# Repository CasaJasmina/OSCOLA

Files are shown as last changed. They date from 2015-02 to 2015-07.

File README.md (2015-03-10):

# OSCOLA
Open Source COnnected LAmp

Oscola is a open source connected lamp designed for the first Casa Jasmina workshop by [Jesse Howard](http://www.jessehoward.net/), Stefano Paradiso and Lorenzo Romagnoli. 

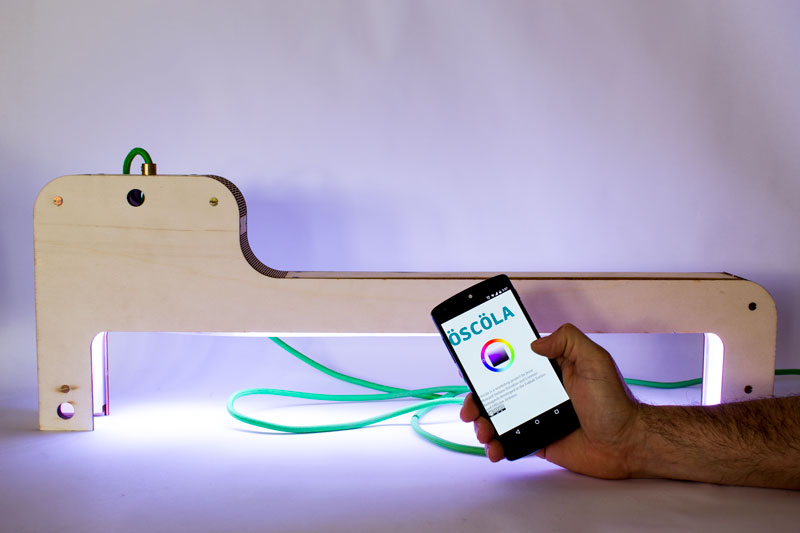
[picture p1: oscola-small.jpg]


Coherently with the Open-Design philosophy, the lamp can be easily reinterpreted and modified according to specific needs. 
The Structure of the lamp is meant to be laser-cutted, and his kept together with screws and bolts; no glue is needed.

The electronic of the lamp is based on Arduino YUN, hence it allows it to connect to the Internet. Via a web-interface the user can change the color of the light.
 
During the workshop participants, made their derivative design. Their codes and cutting files can be found in the "ws projects" folder.



The Arduino code uses MQTT and the [Easy-Arduino-Yun-MQTT-Client](https://github.com/bobbytech/Easy-Arduino-Yun-MQTT-Client) library. In order to control the addressable leds remember to download and install also the [Neopixel library](https://github.com/adafruit/Adafruit_NeoPixel) 

more pics from the workshop [here](https://www.flickr.com/photos/arduino_cc/sets/72157650751710580)

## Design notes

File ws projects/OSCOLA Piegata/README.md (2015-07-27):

# OSCOLA Piegata

CC BY-SA [tamberg](https://twitter.com/tamberg)

Derivative of [https://github.com/CasaJasmina/OSCOLA](https://github.com/CasaJasmina/OSCOLA) licensed CC BY-SA Jesse Howard, Stefano Paradiso and Lorenzo Romagnoli, developed at FabLab Torino and Officine Arduino.



## Arduino Yun Mailbox HTTP API

The OSCOLA Piegata Arduino code is based on the Arduino Yun [Mailbox HTTP API](https://www.arduino.cc/en/Tutorial/MailboxReadMessage), which is simpler than MQTT.

## Testing the API with Curl

Download and install the Curl command line tool from [http://curl.haxx.se/](http://curl.haxx.se/), then type

`$ curl -vX POST http://arduino.local/mailbox/{rrggbb}` e.g.

`$ curl -vX POST http://arduino.local/mailbox/ee6600`

## Using a DIY 3D Tilt Sensor Controller

This project includes a Web page with JS glue code for a [DIY 3D Tilt Sensor](http://www.instructables.com/id/DIY-3D-Tilt-Sensor/) controller - here's a [short video](https://www.youtube.com/v/HGzyO5u3bwg?start=170&end=186&version=3).

## Connecting to the IFTTT Maker Channel

Thanks to the HTTP API, the OSCOLA Piegata can receive Webhook calls from the [IFTTT Maker Channel](blog.ifttt.com/post/121786069098/introducing-the-maker-channel).

To make the Arduino Yun accessible from IFTTT follow the steps in [https://yaler.net/arduino-yun](https://yaler.net/arduino-yun)

Then [clone](https://ifttt.com/recipes/search?q=OSCOLA) or [create a new recipe](https://ifttt.com/myrecipes/personal/new) or [Do app](https://ifttt.com/products/do/button) button using your relay domain in the URL

`http://{RELAY_DOMAIN}.try.yaler.net/mailbox/{rrggbb}` e.g.

`http://gsiot-ffmq-ttd5.try.yaler.net/mailbox/ee6600`

Use *Method* `POST` and *Content Type* `application/x-www-form-urlencoded`, leave *Body* empty.

Here's an example recipe to [light up OSCOLA on sunset](https://ifttt.com/recipes/310542-light-up-oscola-on-sunset) at your location, and one to [switch off OSCOLA on sunrise](https://ifttt.com/recipes/310547-switch-off-oscola-on-sunrise).



IFTTT does not yet allow to publish Do app recpies, so you'll have to create one from scratch.

&nbsp;


# HTTP APIs and Webhooks for an open IoT

Note that OSCOLA, the DIY controller and the IFTTT platform do not know anything about each other.

[HTTP](http://tools.ietf.org/html/rfc2616)(S) [REST](https://de.wikipedia.org/wiki/Representational_State_Transfer) APIs and [Webhooks](https://en.wikipedia.org/wiki/Webhook) enable a loosely coupled, more open Internet of Things.

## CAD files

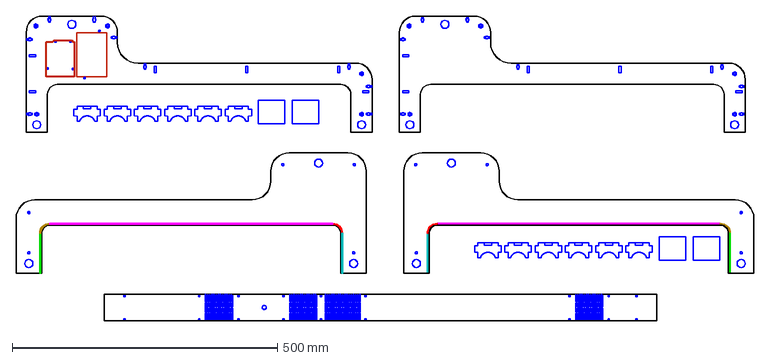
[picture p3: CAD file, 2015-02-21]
cuttingFiles/oscola.dxf
1390.3 x 574.4 mm

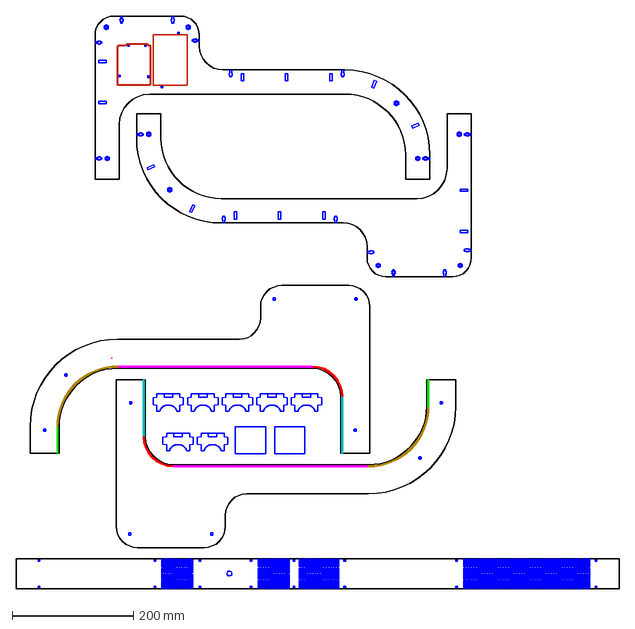
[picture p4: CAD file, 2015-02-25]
ws projects/OSCOLA Piegata/design/oscola_piegata.dxf
994.1 x 944.4 mm

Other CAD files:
ws projects/OSCOLA Piegata/design/oscola_piegata.3dm
ws projects/OSCOLA Piegata/design/oscola_piegata.skp

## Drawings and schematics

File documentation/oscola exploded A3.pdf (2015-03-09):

# OSCOLA

### opensource

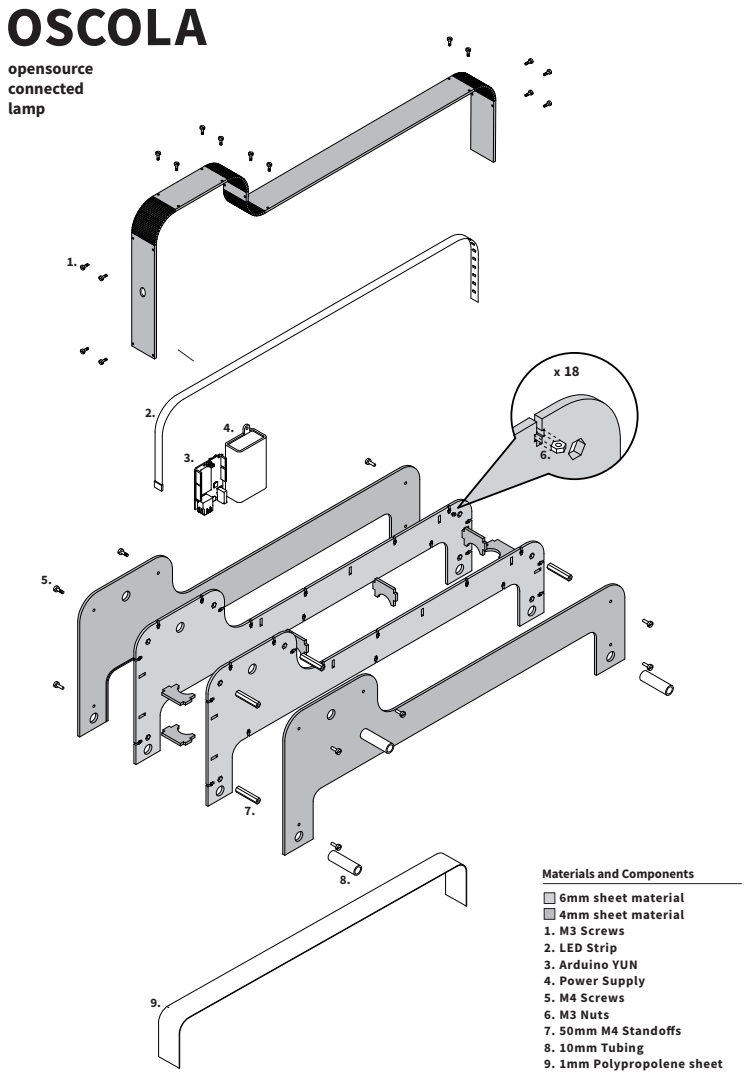
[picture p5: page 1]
connected lamp

Materials and Components
0. 6mm sheet material
0. 4mm sheet material
1. M3 Screws
2. LED Strip
3. Arduino YUN
4. Power Supply
5. M4 Screws
6. M3 Nuts
7. 50mm M4 Standos
8. 10mm Tubing
9. 1mm Polypropolene sheet

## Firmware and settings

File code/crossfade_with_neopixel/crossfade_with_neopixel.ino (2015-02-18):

/*
* Code for cross-fading 3 LEDs, red, green and blue (RGB)
* To create fades, you need to do two things:
*  1. Describe the colors you want to be displayed
*  2. List the order you want them to fade in
*
* DESCRIBING A COLOR:
* A color is just an array of three percentages, 0-100,
*  controlling the red, green and blue LEDs
*
* Red is the red LED at full, blue and green off
*   int red = { 100, 0, 0 }
* Dim white is all three LEDs at 30%
*   int dimWhite = {30, 30, 30}
* etc.
*
* Some common colors are provided below, or make your own
*
* LISTING THE ORDER:
* In the main part of the program, you need to list the order
*  you want to colors to appear in, e.g.
*  crossFade(red);
*  crossFade(green);
*  crossFade(blue);
*
* Those colors will appear in that order, fading out of
*    one color and into the next
*
* In addition, there are 5 optional settings you can adjust:
* 1. The initial color is set to black (so the first color fades in), but
*    you can set the initial color to be any other color
* 2. The internal loop runs for 1020 interations; the 'wait' variable
*    sets the approximate duration of a single crossfade. In theory,
*    a 'wait' of 10 ms should make a crossFade of ~10 seconds. In
*    practice, the other functions the code is performing slow this
*    down to ~11 seconds on my board. YMMV.
* 3. If 'repeat' is set to 0, the program will loop indefinitely.
*    if it is set to a number, it will loop that number of times,
*    then stop on the last color in the sequence. (Set 'return' to 1,
*    and make the last color black if you want it to fade out at the end.)
* 4. There is an optional 'hold' variable, which pasues the
*    program for 'hold' milliseconds when a color is complete,
*    but before the next color starts.
* 5. Set the DEBUG flag to 1 if you want debugging output to be
*    sent to the serial monitor.
*
*    The internals of the program aren't complicated, but they
*    are a little fussy -- the inner workings are explained
*    below the main loop.
*
* April 2007, Clay Shirky <clay.shirky@nyu.edu>
*/

// Output


#include <Adafruit_NeoPixel.h>
#include <avr/power.h>

// Which pin on the Arduino is connected to the NeoPixels?
// On a Trinket or Gemma we suggest changing this to 1
#define PIN            6

// How many NeoPixels are attached to the Arduino?
#define NUMPIXELS      60


Adafruit_NeoPixel pixels = Adafruit_NeoPixel(NUMPIXELS, PIN, NEO_GRB + NEO_KHZ800);


// Color arrays
int black[3]  = { 0, 0, 0 };
int white[3]  = { 100, 100, 100 };
int red[3]    = { 100, 0, 0 };
int green[3]  = { 0, 100, 0 };
int blue[3]   = { 0, 0, 100 };
int yellow[3] = { 40, 95, 0 };
int dimWhite[3] = { 30, 30, 30 };

int color1[3] = {60, 50, 0};
int color2[3] = {100, 100, 100};

// etc.

// Set initial color
int redVal = 0;
int grnVal = 0;
int bluVal = 0;

int wait = 0;      // 10ms internal crossFade delay; increase for slower fades
int hold = 0;       // Optional hold when a color is complete, before the next crossFade
int DEBUG = 0;      // DEBUG counter; if set to 1, will write values back via serial
int loopCount = 60; // How often should DEBUG report?
int repeat = 0;     // How many times should we loop before stopping? (0 for no stop)
int j = 0;          // Loop counter for repeat

// Initialize color variables
int prevR = redVal;
int prevG = grnVal;
int prevB = bluVal;

// Set up the LED outputs
void setup()
{


  if (DEBUG) {           // If we want to see values for debugging...
    Serial.begin(9600);  // ...set up the serial ouput
  }


#if defined (__AVR_ATtiny85__)
  if (F_CPU == 16000000) clock_prescale_set(clock_div_1);
#endif
  // End of trinket special code

  pixels.begin(); // This initializes the NeoPixel library.

}

// Main program: list the order of crossfades
void loop()
{
  crossFade(color1);
  crossFade(color2);


  if (repeat) { // Do we loop a finite number of times?
    j += 1;
    if (j >= repeat) { // Are we there yet?
      exit(j);         // If so, stop.
    }
  }
}

/* BELOW THIS LINE IS THE MATH -- YOU SHOULDN'T NEED TO CHANGE THIS FOR THE BASICS
*
* The program works like this:
* Imagine a crossfade that moves the red LED from 0-10,
*   the green from 0-5, and the blue from 10 to 7, in
*   ten steps.
*   We'd want to count the 10 steps and increase or
*   decrease color values in evenly stepped increments.
*   Imagine a + indicates raising a value by 1, and a -
*   equals lowering it. Our 10 step fade would look like:
*
*   1 2 3 4 5 6 7 8 9 10
* R + + + + + + + + + +
* G   +   +   +   +   +
* B     -     -     -
*
* The red rises from 0 to 10 in ten steps, the green from
* 0-5 in 5 steps, and the blue falls from 10 to 7 in three steps.
*
* In the real program, the color percentages are converted to
* 0-255 values, and there are 1020 steps (255*4).
*
* To figure out how big a step there should be between one up- or
* down-tick of one of the LED values, we call calculateStep(),
* which calculates the absolute gap between the start and end values,
* and then divides that gap by 1020 to determine the size of the step
* between adjustments in the value.
*/

int calculateStep(int prevValue, int endValue) {
  int step = endValue - prevValue; // What's the overall gap?
  if (step) {                      // If its non-zero,
    step = 1020 / step;            //   divide by 1020
  }
  return step;
}

/* The next function is calculateVal. When the loop value, i,
*  reaches the step size appropriate for one of the
*  colors, it increases or decreases the value of that color by 1.
*  (R, G, and B are each calculated separately.)
*/

int calculateVal(int step, int val, int i) {

  if ((step) && i % step == 0) { // If step is non-zero and its time to change a value,
    if (step > 0) {              //   increment the value if step is positive...
      val += 1;
    }
    else if (step < 0) {         //   ...or decrement it if step is negative
      val -= 1;
    }
  }
  // Defensive driving: make sure val stays in the range 0-255
  if (val > 255) {
    val = 255;
  }
  else if (val < 0) {
    val = 0;
  }
  return val;
}

/* crossFade() converts the percentage colors to a
*  0-255 range, then loops 1020 times, checking to see if
*  the value needs to be updated each time, then writing
*  the color values to the correct pins.
*/

void crossFade(int color[3]) {
  // Convert to 0-255
  int R = (color[0] * 255) / 100;
  int G = (color[1] * 255) / 100;
  int B = (color[2] * 255) / 100;

  int stepR = calculateStep(prevR, R);
  int stepG = calculateStep(prevG, G);
  int stepB = calculateStep(prevB, B);

  for (int i = 0; i <= 1020; i++) {
    redVal = calculateVal(stepR, redVal, i);
    grnVal = calculateVal(stepG, grnVal, i);
    bluVal = calculateVal(stepB, bluVal, i);


    for (int i = 0; i < NUMPIXELS; i++) {

      // pixels.Color takes RGB values, from 0,0,0 up to 255,255,255
      pixels.setPixelColor(i, pixels.Color(redVal, grnVal, bluVal)); // Moderately bright green color.

      // This sends the updated pixel color to the hardware.

      //delay(delayval); // Delay for a period of time (in milliseconds).

    }
    pixels.show();

    delay(wait); // Pause for 'wait' milliseconds before resuming the loop

    if (DEBUG) { // If we want serial output, print it at the
      if (i == 0 or i % loopCount == 0) { // beginning, and every loopCount times
        Serial.print("Loop/RGB: #");
        Serial.print(i);
        Serial.print(" | ");
        Serial.print(redVal);
        Serial.print(" / ");
        Serial.print(grnVal);
        Serial.print(" / ");
        Serial.println(bluVal);
      }
      DEBUG += 1;
    }
  }
  // Update current values for next loop
  prevR = redVal;
  prevG = grnVal;
  prevB = bluVal;
  delay(hold); // Pause for optional 'wait' milliseconds before resuming the loop
}

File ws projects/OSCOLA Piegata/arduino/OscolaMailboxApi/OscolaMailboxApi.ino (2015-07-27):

// Control the OSCOLA connected lamp via the Arduino Yun Mailbox
// REST API: Try HTTP POST http://OSCOLA_LOCAL_IP/mailbox/rrggbb
// For remote Web & SSH access see https://yaler.net/arduino-yun

// Based on http://arduino.cc/en/Tutorial/MailboxReadMessage
// and NeoPixel Ring simple sketch, Copyright (c) 2013, Shae Erisson
// and https://github.com/CasaJasmina/OSCOLA/ (c) 2015, Jesse Howard,
// Stefano Paradiso and Lorenzo Romagnoli

// Copyright (c) 2015, @tamberg
// Licensed under GPLv3

#include <Mailbox.h>
#include <Adafruit_NeoPixel.h>

#define PIN 6
#define NUMPIXELS 47

Adafruit_NeoPixel pixels = Adafruit_NeoPixel(
  NUMPIXELS, PIN, NEO_GRB + NEO_KHZ800);

int color[3] = {0, 0, 0};

void convertHexColor(String hexColor) {
  long c = (long) strtol(&hexColor[0], NULL, 16);
  color[0] = c >> 16;
  color[1] = c >> 8 & 0xFF;
  color[2] = c & 0xFF;
}

void setPixelsColor(int r, int g, int b) {
  for (int i = 0; i < NUMPIXELS; i++) {
    pixels.setPixelColor(i, pixels.Color(r, g, b));
  }
  pixels.show();
}

void setup() {
  pixels.begin();
  for (int i = 0; i < 100; i++) {
    setPixelsColor(i, i, i);
    delay(100);
  }
  Bridge.begin();
  Mailbox.begin();
  Serial.begin(9600);
  //while (!Serial);
}

void loop() {
  String message;
  while (Mailbox.messageAvailable()) {
    Mailbox.readMessage(message);
    Serial.println(message);
    convertHexColor(message);
    setPixelsColor(color[0], color[1], color[2]);
  }
}

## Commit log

2015-02-21 OSCOLA cutting files
    [oscola.dxf]
2015-02-21 fixed arduino sketch
2015-02-25 Moved OscolaMailboxApi.ino, added design and web files.
    [oscola_piegata.3dm, oscola_piegata.dxf, oscola_piegata.skp]
2015-03-03 added arduino code for the supsi lamp
